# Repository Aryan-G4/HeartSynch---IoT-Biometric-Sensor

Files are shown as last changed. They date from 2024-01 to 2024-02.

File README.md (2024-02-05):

# HeartSynch - An IoT Wearable Biometric sensor
## Designed by Aryan Ghosh, Chris Koehlmann, Joseph Carnide, and Simon Louis
Readme currently under construction!

HeartSynch is a portable and wearable biometric sensor and emergency device that allows a user's family to remotely monitor vitals and be contacted easily in the case of an emergency.



https://github.com/Aryan-G4/HeartSynch---IoT-Biometric-Sensor/assets/119129454/10078840-45ad-4ce8-8d1b-7f7a4a50caf8



## Introduction
This project hit home for us and was inspired based on a teammate's experiences living with his grandma. His grandmother is 85 years old and is cared for by him, his parents and his siblings. Due to her age and medical conditions, someone always has to be home to take care of her, but even that does not ensure an immediate response like last year when she fell in the bathroom, and neither he nor his family knew for an hour. This is what HealthSync aims to solve. A portable, easy-to-use, cost-friendly device so that family members of all classes can be immediately alerted when their elderly family members get injured or have a medical emergency so that this never happens again.

## Table of Contents
- [Project Overview](#project-overview)
- [Electrical Setup](#electrical-Component)
- [Software Setup](#software-Component)
- [Hardware Setup](#hardware-Component)
- [Early Work](#early-work)

## Project Overview
This project was created to solve a problem we see in the medical field today. All designs and ideation are entirely original and created by the four contributing members of this repository. 

HeartSynch is a wearable device using an ESP32 development board to sense a user's heart rate, blood oxygen, temperature, and movement and displays all of these metrics on a website. This website, with the purchase of a domain, can be accessed by any member of the user's family, showing them important biometric data in real time and alerting them when the sensor detects a biometric that is in an unsafe range (ex., A constant heart rate of 60bpm). This device allows for a more convenient safety net for users with health risks. 


## Electrical Component


The Electrical component boasts an ESP32 microcontroller development board mainly due to its built-in WiFi features. The ESP32 is powered by a 9V battery that is regulated into a 5V, 3.3V and GND signal. The ESP32 requires a 5V input to run and all sensors, GPIO pins, and I2C pins require 3.3V. The electrical system made use of the MPU-6050 6-axis accelerometer used for fall and injury protection. Additionally we used the MAX30102 sensor to detect readings in heart rate, blood oxygen concentration, and temperature: all important biometrics to monitor for someone in at a risk of general health. Both sensors used I2C, connecting to the same ports of the ESP32. 

### Circuit Schematic to be implemented on the breadboard
electrical schematic

Using KiCad, I created a schematic of the electrical system that had to be implemented to allow the ESP32 to pass all electrical rules checks and to properly recieve data from all sensors. 
To ensure rapid production and prototyping, I used a breadboard to assemble the circuit shown in the schematic and colour-coded wires to allow for easy installation, debugging, and removal of wires. 


## Hardware Component
The mechanical design of our system revolved around the constraints created by the electrical components we had to use. The chassis was built around the electronic components and went through multiple rounds of iteration to ensure all components were secure and the device was as comfortable as possible without sacrificing durability. All parts of the chassis are 3d printed using PLA and all files are included under the "mechanical" folder. The mechanical design features a ratcheting ladder strap that allows the user to wear and remove the device extremely easily while ensuring the device is secured.


### Solidworks model

To ensure all parts fit together and that no time was wasted during construction. We thoroughly planned out the mechanical design using Solidworks. This also ensured that the device fit a wide range of users. 

## Software Component



Using HTML, CSS, JavaScript, and C, our team was able to collect data from the sensors into the ESP32. We then used the ESP32 to host a local webpage to display and inform users of current biometric data. The webpage we created works on both PC and Mobile allowing for a seamless user experience.

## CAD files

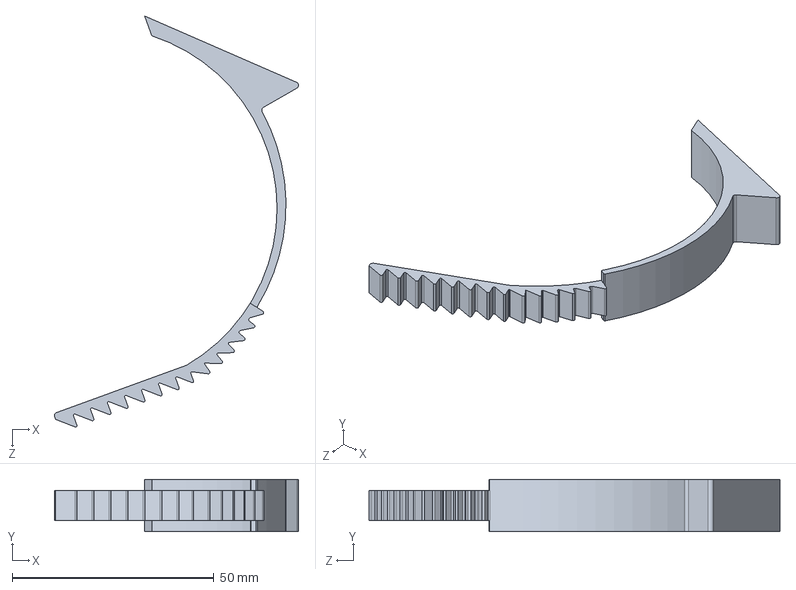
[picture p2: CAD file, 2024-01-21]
Mechanical/solidworks/Arm Clamp inner v3.4.SLDPRT
60.6 x 13.0 x 102.0 mm

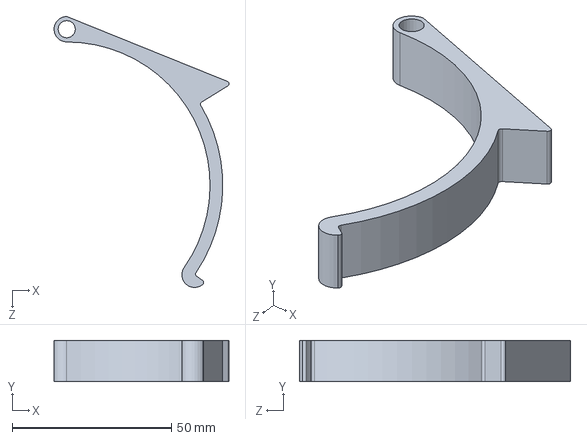
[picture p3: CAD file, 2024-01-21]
Mechanical/solidworks/Arm Clamp v5.SLDPRT
55.0 x 13.0 x 85.1 mm

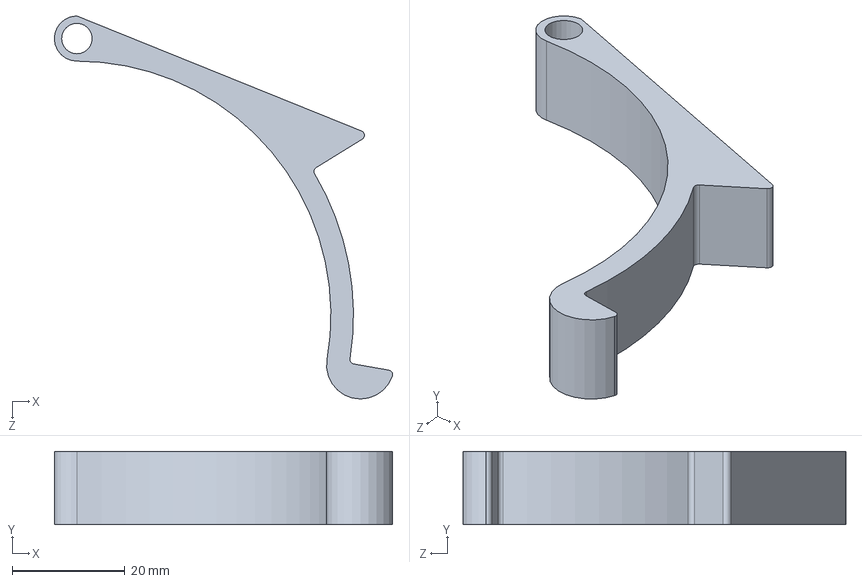
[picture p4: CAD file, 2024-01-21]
Mechanical/solidworks/Arm Clamp - short v6.SLDPRT
59.9 x 13.0 x 67.9 mm

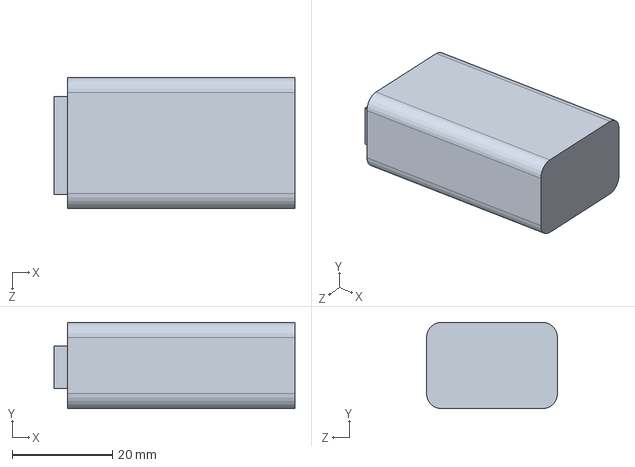
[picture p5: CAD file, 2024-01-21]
Mechanical/solidworks/9V battery.SLDPRT
48.0 x 17.2 x 26.1 mm

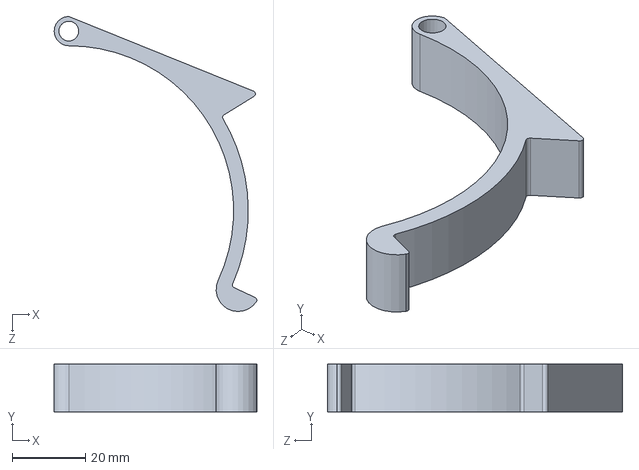
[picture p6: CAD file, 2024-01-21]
Mechanical/solidworks/Arm Clamp - medium v6.SLDPRT
55.3 x 13.0 x 80.5 mm

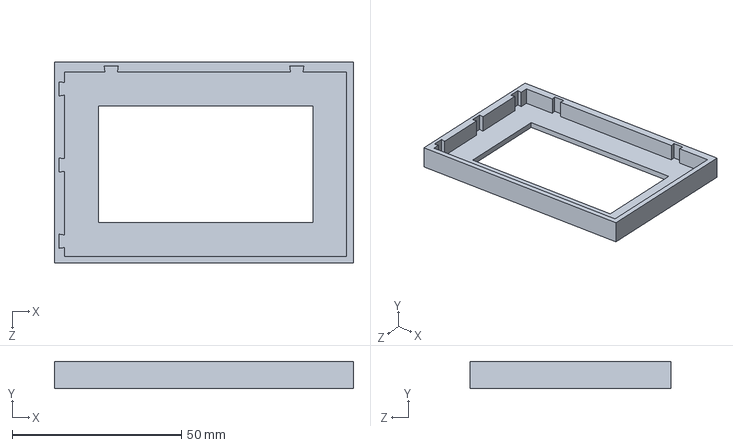
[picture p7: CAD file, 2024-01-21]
Mechanical/solidworks/BreadMount v1.SLDPRT
88.3 x 8.00 x 59.5 mm

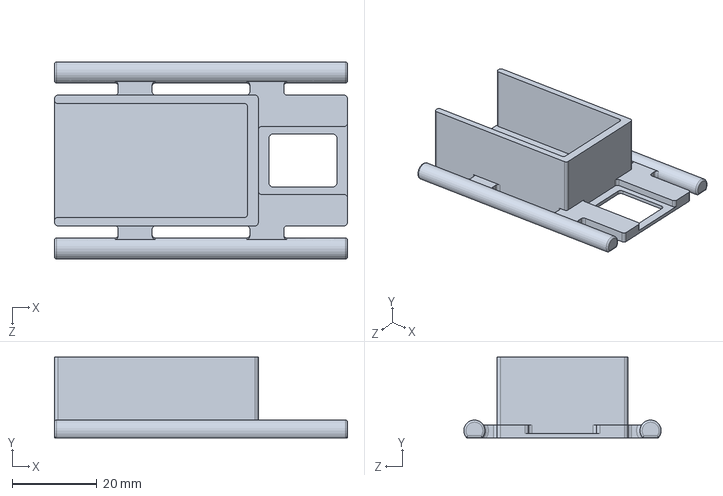
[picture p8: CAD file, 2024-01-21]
Mechanical/solidworks/HRand9V mount v2.SLDPRT
69.0 x 19.0 x 46.5 mm

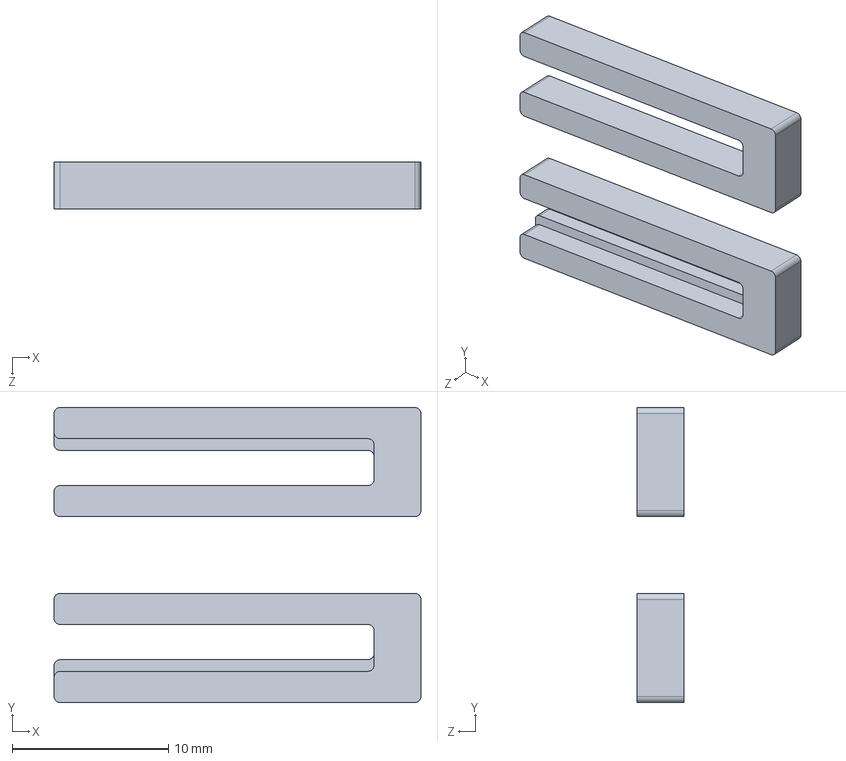
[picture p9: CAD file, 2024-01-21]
Mechanical/solidworks/HRclip v8.SLDPRT
23.5 x 18.9 x 3.00 mm

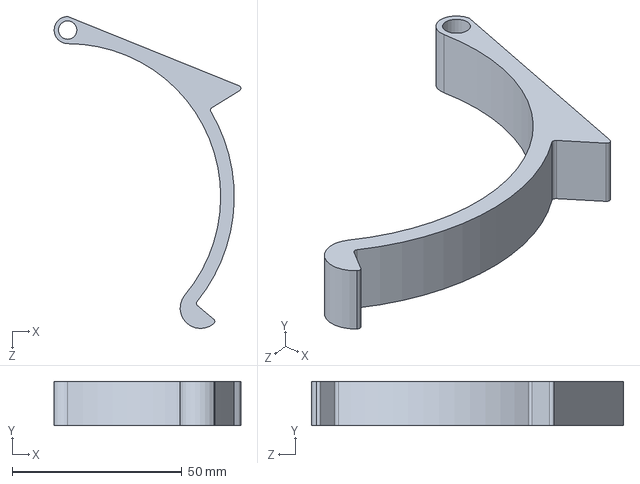
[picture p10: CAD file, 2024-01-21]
Mechanical/solidworks/Arm Clamp - long v6.SLDPRT
55.0 x 13.0 x 91.8 mm

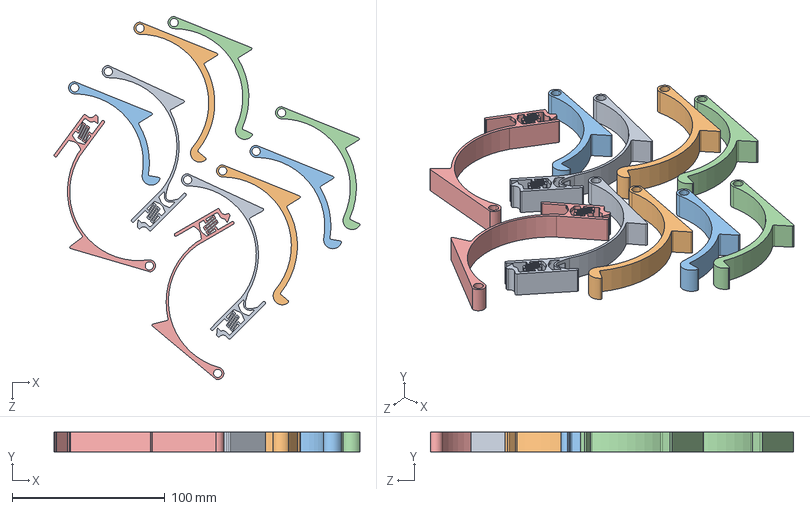
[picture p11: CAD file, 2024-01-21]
Mechanical/solidworks/ArmBandforPrinting v5.STEP
200.6 x 13.0 x 238.0 mm
Arm Clamp v3.2 x 2
Arm Clamp - long v6 x 2
Arm Clamp - short v6 x 2
Arm Clamp - medium v6 x 2
Arm Clamp v3.3 x 2

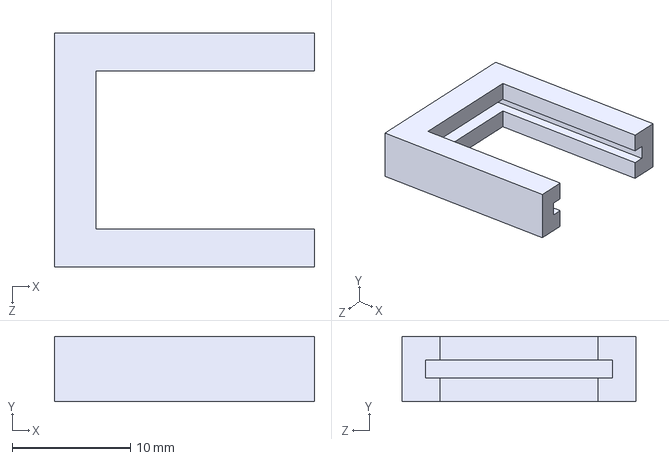
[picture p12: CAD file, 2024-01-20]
Mechanical/solidworks/HeartSense Mount v1.STEP
22.0 x 5.50 x 19.8 mm

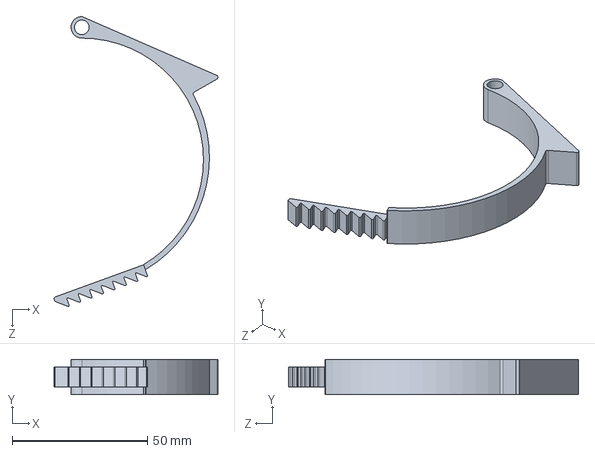
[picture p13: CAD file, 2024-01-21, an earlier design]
Mechanical/solidworks/Arm Clamp inner v3.2.SLDPRT
60.6 x 13.0 x 107.3 mm

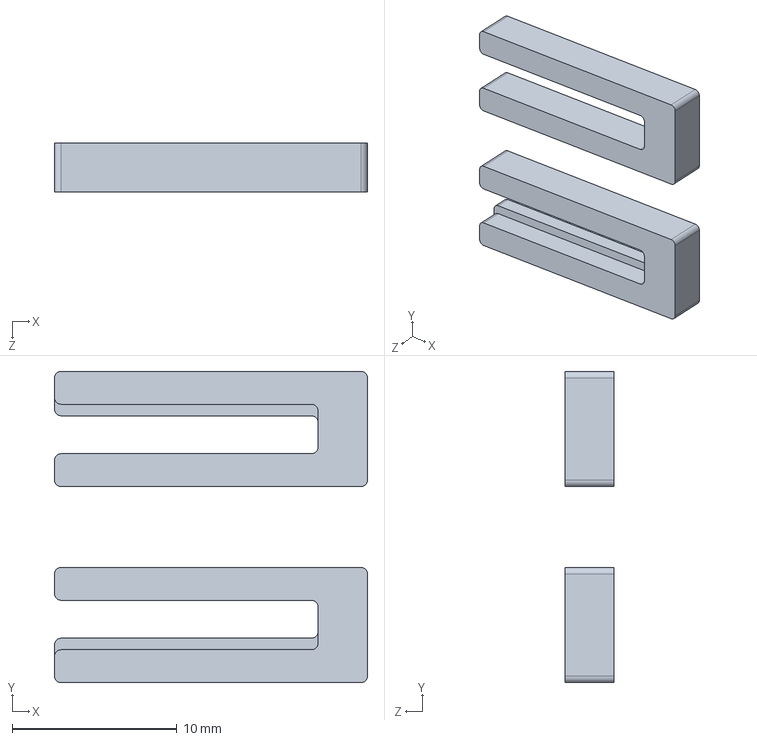
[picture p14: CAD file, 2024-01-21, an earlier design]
Mechanical/solidworks/HRclip v5.SLDPRT
19.0 x 18.9 x 3.00 mm

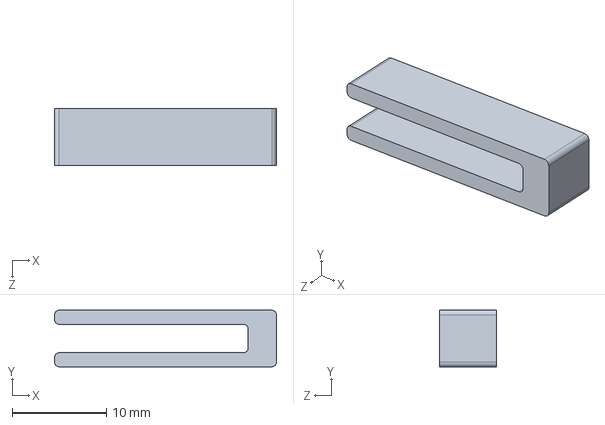
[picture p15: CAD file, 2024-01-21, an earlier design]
Mechanical/solidworks/HRclip v1.SLDPRT
23.5 x 6.00 x 6.00 mm

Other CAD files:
Mechanical/solidworks/Arm Clamp inner v3.1.SLDPRT
Mechanical/solidworks/Arm Clamp v3.3.SLDPRT
Mechanical/solidworks/Arm Clamp v2.SLDPRT
Mechanical/solidworks/Arm Clamp v3.SLDPRT
Mechanical/solidworks/Arm Clamp inner v3.SLDPRT
Mechanical/solidworks/Arm Clamp v1.SLDPRT
Mechanical/solidworks/Arm Clamp v3.1.SLDPRT
Mechanical/solidworks/Arm Clamp v3.2.SLDPRT
Mechanical/solidworks/Arm Clamp v4.SLDPRT
Mechanical/solidworks/ArmBandforPrinting v1.SLDASM
Mechanical/solidworks/ArmBandforPrinting v1.STEP
Mechanical/solidworks/ArmBandforPrinting v2.SLDASM
Mechanical/solidworks/ArmBandforPrinting v2.STEP
Mechanical/solidworks/ArmBandforPrinting v3.SLDASM
Mechanical/solidworks/ArmBandforPrinting v3.STEP
Mechanical/solidworks/ArmBandforPrinting v4.SLDASM
Mechanical/solidworks/ArmBandforPrinting v4.STEP
Mechanical/solidworks/ArmBandforPrinting v5.SLDASM
Mechanical/solidworks/HRand9V mount v1.SLDPRT
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

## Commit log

2024-01-20 Bread Board Mount Test1 file
    simple box to test the bread board dovetail connection in 3d printing
    [BreadMount v1.SLDPRT]
2024-01-20 Heart Rate Senser slot mount test
    First 3d print file to test Heart Rate Senser slot mount idea
    [HeartSense Mount v1.STEP]
2024-01-21 Full Assembly for printing v1
    Print file that contains all the parts for the first version.
    [ArmBandforPrinting v1.STEP]
2024-01-21 Straps for printing v2
    A whole load of new straps, some are risky.
    [ArmBandforPrinting v2.STEP]
2024-01-21 2nd Prototype for ratchet clips
    The 3d print file for the 2nd version of the clip ratchet design.
    [ArmBandforPrinting v3.STEP]
2024-01-21 Fourth Print for arms and clips
    Fixed width issue with arm teeth, incudes clips to secure heart rate sensor
    [ArmBandforPrinting v4.STEP]
2024-01-21 Final arm band designs for printing
    Includes elastic band types and tweaked ratchet designs.
    [ArmBandforPrinting v5.STEP]
2024-01-21 added schematic
2024-01-21 All SolidWorks files
    [9V battery.SLDPRT, Arm Clamp - long v6.SLDPRT, Arm Clamp - medium v6.SLDPRT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]
2024-01-21 long toothed clamp
    [Arm Clamp inner v3.4.SLDPRT]
